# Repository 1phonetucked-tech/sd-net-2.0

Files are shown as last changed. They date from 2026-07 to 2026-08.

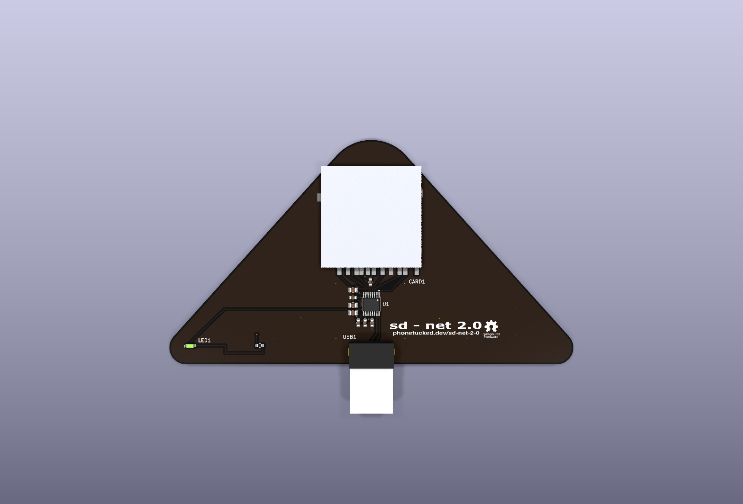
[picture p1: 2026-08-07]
fab/v2.0-kicad/sd-net-2.0-placement-reference.png

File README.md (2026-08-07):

# sd - net 2.0

full-size USB SD card reader > USB-A plug for end user connect > 13 placements across 7 line items in between.

   
rev 2.0 is certified open source hardware by the [Open Source Hardware Association](https://certification.oshwa.org/us002843.html) > UID US002843 > certified 2026-08-07

hardware, everything in `hardware/` and `fab/` > CERN-OHL-S-2.0 > distribute a variant and its design files must be shared under the same terms  
documentation, everything in `docs/` > CC-BY-SA-4.0 > credit the source, share adaptations alike  
software, the generators in `tools/` > GPL-3.0 > see `tools/LICENSE`

| | |
|---|---|
| controller | Genesys Logic GL823K, SSOP-16, LCSC C284879 |
| board | 116.12 × 64.98 mm, 4 layers, 1.6 mm, ENIG |
| finish | black soldermask, white legend |
| placements | 13, of which 12 SMT and 1 through-hole |
| interface | USB 2.0 high speed, SD 4-bit mode |

boards are exclusively given away > not sold.

**shoutout to [PCBWay](https://www.pcbway.com/) who is sponsoring the rev 2.0
run > five boards, fabricated and assembled**

## specifications

**supply**  
1 external rail. GL823K's only rated input is 5 V from VBUS (multimeter tested). VDD and VDDA are outputs of an on-chip band-gap regulator and carry decoupling only > never an external feed. card power is a separate switched net driven from the controller's current-limited output, with its bulk capacitance at the socket so card inrush never reaches the USB PHY rail. **four nets > eight capacitors > no external regulator**  
review [`docs/POWER-DESIGN.md`](docs/POWER-DESIGN.md)

**land patterns**  
KiCad ships no footprint matching any of the three parts on this board > SD-006M (SD slot) > AM90 (USB) > Everlight 12-215SYGC/S530-E2/TR8 (LED). i opted out of pulling them from easyeda2kicad and generated them from the manufacturers' recommended land patterns instead > dimension by dimension > 3D models the same way. every value is recorded in [`docs/LAND-PATTERNS.md`](docs/LAND-PATTERNS.md) > the USB plug's shell tabs sit in correctly sized plated slots rather than oversized round holes > those tabs are the only thing anchoring a board that cantilevers roughly 75 mm out of a host port

**outline**  
isosceles triangle > symmetric about the axis the apex arc and all three connectors sit on > both sides 70.175 mm at 48.007 degrees, with the diagonals constructed as true tangents to the corner fillets

**no external clock**  
controller (GL823K-HCY04) has an on-chip clock source > 12 MHz crystal is not required.

**no card detect**  
by design. controller detects cards by polling the SD bus, which is why the socket's mechanical CD and WP are no connect

## currently

design is DRC clean.  
0 violations and 0 unconnected  
netlist is checked against intent > supply topology is confirmed on hardware at 3.38 V

**rev 2.0 has not been fabricated (yet)**  
[`docs/STATUS.md`](docs/STATUS.md) lists what is verified > what is not > and the checks to run on first articles.  
review before ordering

## layout

| Path | |
|---|---|
| `hardware/` | KiCad 10 project: schematic, PCB, footprints, 3D models |
| `fab/v2.0-kicad/` | Gerbers, drill, BOM, pick-and-place, assembly drawing |
| `docs/` | Power design, land patterns, status |
| `tools/` | Generators and checks |
| `branding/` | OSHW mark and the KiCad colour theme used for the schematic PDF |

## building

the package in `fab/v2.0-kicad/` uploads as-is. Its `README.md` states the
stackup, the plated slots, the non-plated holes and the impedance target for the
fab. To regenerate:

```sh
./tools/gen_fab.py                    # fabrication package
./tools/gen_footprints.py             # footprints
./tools/gen_3dmodels.py               # 3D models
./tools/verify_netlist.py             # netlist against intent
```

`gen_schematic.py` and `gen_pcb.py` built the original KiCad files > kept as a record only > running either overwrites the current board

**do not run `Tools → Update Footprints from Library` in the PCB editor. KiCad
stores pad angles absolutely & `U1` sits at 270 degrees > updating from the library strips those angles and shorts the part**  
*also explained in [`docs/LAND-PATTERNS.md`](docs/LAND-PATTERNS.md)*

created by (1)PhoneTucked.

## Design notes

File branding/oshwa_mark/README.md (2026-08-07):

# Open-source-hardware logo — silkscreen artwork

Prepared for **sd - net** (the plain gear needs no number).

Black (single silkscreen color) version of the classic open-source-hardware gear,
recolored from your `oshw-logo.svg` (OSHW teal `#0099B0` → pure black).

| File | Use |
|---|-----|
| `oshw_gear_13mm.svg` | **Import this** into KiCad — same artwork with real-world dimensions stamped on it (13.0 × 13.661 mm), so `File → Import → Graphics` sizes it correctly instead of guessing a DPI |
| `oshw_gear_black.svg` | Unsized original |
| `oshw_gear_black.png` | 1000 px raster fallback if the SVG import ever misbehaves |

**Target size: 13 mm wide, 10 mm absolute floor.** An earlier version of this file
said 8–12 mm, which was wrong: the artwork is not gear-only, it carries the
"open source hardware" wordmark underneath, and the wordmark is what sets the
minimum. At 13 mm total the wordmark's two lines are roughly 2.2 mm each. Go
much below 10 mm and the thin strokes drop under PCBWay's 0.15 mm silkscreen
minimum, where they print broken or vanish.

Place on a copper-free area — silkscreen over exposed copper gets clipped.
The plain gear logo is free to use on any design that meets the open-source-hardware
definition — no registration or UID required.

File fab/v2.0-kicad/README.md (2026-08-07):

# sd - net 2.0, fabrication package

open-source USB SD card reader. CERN-OHL-S-2.0.
Repository: https://github.com/1phonetucked-tech/sd-net-2.0

| | |
|---|---|
| Board size | **116.12 × 64.98 mm**, shaped outline, not a rectangle |
| Layers | 4 |
| Thickness | 1.6 mm |
| Copper | 1 oz (35 µm) outer and inner |
| Surface finish | **ENIG** |
| Soldermask | **black** |
| Silkscreen | **white** |
| Min track / clearance | 0.20 mm / 0.20 mm |
| Min via | 0.60 mm pad, 0.30 mm drill |
| Placements | **13**, across 7 line items |

## Files

| File | |
|---|---|
| `sd-net-2.0-gerber.zip` | Gerbers + Excellon drill, flat, Protel extensions |
| `sd-net-2.0-bom.csv` | BOM with MPN, manufacturer and LCSC part numbers |
| `sd-net-2.0-cpl.csv` | Pick-and-place |
| `sd-net-2.0-assembly.pdf` | Assembly drawing, legend, part outlines, designators |
| `sd-net-2.0-placement-reference.png` | Render of the finished board |
| `sd-net-2.0-schematic.pdf` | Schematic, for reference |

## Please note when quoting

**1, The outline is not rectangular.** An isosceles triangle with a 13.54 mm
radius arc across the apex and 4.85 mm fillets on the bottom two corners.
Please confirm any profiling or CNC routing charge is included.

**2, One through-hole part, and we do want it populated.** `USB1` is an AM90
right-angle USB-A **male plug**, 6 joints. It falls outside standard SMT
assembly, so please add the hand-soldering as a line item and quote it, rather
than shipping the plug loose. Every board should arrive with `USB1` fitted.
Everything else is SMT.

**3, Two plated slots.** `USB1` MH1/MH2 are **0.90 × 2.25 mm plated slots**,
not round holes. They take the plug's shell tabs and carry the mechanical load,
so please do not substitute round drills.

They are in the drill file, not in the Gerber layers. `sd-net-PTH.drl` cuts them
as Excellon G85 routed slots on tool `T2C0.900`, each routing 1.350 mm along Y
from a centre of Y -95.855, at X 94.155 (MH1) and X 82.445 (MH2). The copper is
on all four layers: obround aperture 1.70 × 3.05 mm flashed at the same two
centres, mask opened to match, both on GND. They are the two oval pads either
side of the four round USB pins. `sd-net-PTH-drl_map.pdf` marks them as well. If
your CAM prefers M15/M16 routed slots or a separate rout layer, say so and we
will send a new drill file.

**4, Four holes must NOT be plated.** `sd-net-NPTH.drl` holds 2 × Ø1.00 mm
(USB plug locating pegs) and 2 × Ø1.60 mm (SD socket pegs). Plating them will
prevent both connectors from seating.

**5, Impedance, as a courtesy check.** `USB_DP` / `USB_DM` on F.Cu are
intended as a 90 Ω differential pair: 0.30 mm wide, 0.346 mm gap, referenced to
In1.Cu, solved against your standard 4-layer 1.6 mm stackup (7628 prepreg,
0.1855 mm after lamination, Dk 4.74). The pair is only ~10 mm long, so this is
not critical, but if your stackup wants a different width or gap, please say
and we will adjust. Note the pair threads a 1.475 mm corridor with 0.265 mm
either side, so widening it needs a layout change on our end.

**6, Please check the CPL rotations against your convention.** The
pick-and-place is KiCad's native output: millimetres, Y negative, rotations in
KiCad's frame. Orientation is the single largest risk on this board, `U1` is
an SSOP-16 where pin 1 must be right, and `LED1` is polarised. If your tooling
expects a different rotation origin, please tell us rather than assuming.

## Two requests

**Five boards first, not the full run.** This revision has never been
fabricated. We would rather find problems on five.

**A photo of the first assembled board before the rest are run.** Compare it
against `sd-net-2.0-placement-reference.png`. Assembly orientation is the
largest remaining risk in this design, and a photo catches it for free.

## About the project

Boards are **given away, not sold**, this is an open-hardware project under
CERN-OHL-S-2.0. Happy to credit PCBWay wherever the project is published.

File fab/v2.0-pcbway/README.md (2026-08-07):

# sd - net 2.0, PCBWay variant

Vendor-specific build of the same board. **Nothing here is a different design.**
Every layer is byte-for-byte identical to `fab/v2.0-kicad/` once Gerber
attribute and comment lines are stripped, and the drill coordinates are the
same to the micron.

Anyone fabricating this board elsewhere should use **`fab/v2.0-kicad/`**, which
is the canonical package. This folder exists because PCBWay asked for two
specific things during the 2026-08 file audit.

## What is different, and why

**1, Gerbers are plain RS-274X, not X2.** PCBWay asked for RS-274X on
2026-08-05. Exported with `--no-x2`, which removes the `%TF` / `%TA` / `%TO` /
`%TD` extended commands. `--no-netlist` is deliberately **not** used: it is not
needed for RS-274X compliance and it would delete the net names. They survive
as ordinary `G04` comments, so netlist-based DFM still works.

**2, The `.gbrjob` file is omitted.** It is part of the X2 family and its
presence invites the same question the RS-274X conversion was meant to settle.

**3, The two `USB1` slots ship in alternative encodings.** They are the only
non-round feature on the board, and the only part of the package queried during
the audit. `sd-net-2.0-drill-alternates.zip` holds the same two slots written
two other ways, so a CAM system can take whichever slot convention it prefers.

## Files

| File | |
|---|---|
| `sd-net-2.0-gerber-rs274x.zip` | Gerbers + Excellon drill, RS-274X, no `.gbrjob` |
| `sd-net-2.0-drill-alternates.zip` | Slot alternatives, see below |

Inside `sd-net-2.0-drill-alternates.zip`:

| File | |
|---|---|
| `sd-net-PTH-M15M16.drl` | Plated drill with the slots as M15/M16 routed slots instead of `G85`. Identical to `sd-net-PTH.drl` in every other respect |
| `sd-net-PTH-drl.gbr` | Drill data plotted as a Gerber layer, so every hole is visible in an ordinary viewer |
| `sd-net-NPTH-drl.gbr` | The same, non-plated |

**Only one plated drill file may be loaded**, either `sd-net-PTH.drl` from the
main zip or `sd-net-PTH-M15M16.drl` from the alternates. Both describe the same
two slots, so loading both would double them.

The two `.gbr` files are for viewing and cross-checking only. They are not a
fabrication layer and must not be used as one.

## The slots

All three encodings describe one geometry: a 0.90 mm tool travelling 1.350 mm
along Y, giving a **0.90 x 2.25 mm plated slot**, long axis vertical.

| | Centre | Extent along Y |
|---|---|---|
| MH1 | X 94.155, Y -95.855 | -94.730 → -96.980 |
| MH2 | X 82.445, Y -95.855 | -94.730 → -96.980 |

Copper is an obround 1.70 x 3.05 mm flashed at the same two centres on all four
layers, mask opened to match, both on GND.

## Hole inventory

| File | Tool | Size | Count | |
|---|---|---|---|---|
| PTH | T1 | Ø0.300 mm | 20 | vias |
| PTH | T3 | Ø1.001 mm | 4 | `USB1` signal pins |
| PTH | T2 | 0.90 x 2.25 mm slot | 2 | `USB1` shell tabs |
| NPTH | T1 | Ø1.000 mm | 2 | `USB1` locating pegs |
| NPTH | T2 | Ø1.600 mm | 2 | SD socket pegs |

26 plated including the two slots, 4 non-plated, 30 total. **The four NPTH must
stay unplated** or neither connector will seat.

## Regenerating

    ./tools/gen_fab.py --pcbway

Builds this folder and touches nothing else. The quoting notes, BOM, CPL and
assembly drawing are not duplicated here: they live in `fab/v2.0-kicad/` and
are not vendor-specific.

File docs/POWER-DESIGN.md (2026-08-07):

# Power design

The GL823K takes a single external supply. Everything else on the board is
generated inside the chip.

Section and table numbers below refer to the GL823K datasheet rev 1.05. That
document is Genesys Logic's and is not redistributed here: request it through
the vendor, or through LCSC part C284879.

## Supply topology

Four nets, each with its own decoupling, and no external connection between
them.

: `+5V` : `USB1.1` to `U1.10`. The only external supply. C1 10 uF + C4 100 nF
: `VDD` : `U1.9`. Regulator output. Decouple only. C2 10 uF + C5 100 nF
: `VDDA` : `U1.13`. Regulator output feeding the USB PHY. Decouple only, keep
  the loop tight. C6 + C8 100 nF
: `VCARD` : `U1.8` to `CARD1.4`. Switched output. C3 10 uF + C7 100 nF, placed
  at the socket

## Why VDD and VDDA are not supplied externally

The datasheet lists exactly one supply. Table 5.2 gives an operating range of
+4.75 V to +5.25 V, and Table 5.3 lists one entry, `V5`. Neither VDD nor VDDA
appears anywhere in the electrical characteristics. Section 4.6 describes an
on-chip 5 V to 3.3 V band-gap regulator supplying the USB PHY and PMOS, and
section 4.7 describes on-chip power MOSFETs for memory card power.

VDD and VDDA are therefore outputs. Driving them from an external rail would
fight the internal regulator.

Confirmed on hardware, 2026-08-02. With only 5 V applied, VBUS measured at
5.17 V, the 3.3 V node reads 3.38 V, which is within the tolerance expected of a
band-gap reference. Nothing external supplies that node, so the regulator is
producing it.

The Rev 1.05 datasheet contains no typical application circuit and no
recommended decoupling values. The topology above follows from the electrical
tables; the capacitor values are engineering judgement.

## Why VDD and VDDA are not tied to each other

Decouple each separately at its own pin and run no external link between them.
This holds under either internal arrangement:

: If they are internally common, an external link is redundant and omitting it
  costs nothing
: If they are internally separate, an external link defeats that isolation and
  couples digital and card-interface switching noise into the USB 2.0 PHY rail

## Card power

`PMOS`, pin 8, is a switched current-limited output rated 200 mA. It is not a
supply rail and must drive the card only.

Bulk and high-frequency capacitance for the card sits at the socket rather than
at the controller, so card inrush is absorbed locally and does not reach VDD or
VDDA.

## Clock

No external crystal. The GL823K contains an on-chip clock source, so no 12 MHz
oscillator is required.

## LED

`R1`, 220 R, is fed from VDD, so the LED runs on 3.3 V and requires a forward
voltage at or below roughly 2.4 V. The specified part is a yellow-green AlInGaP
device at 1.7-2.4 V, giving about 5.5 mA. A pure green InGaN LED with a 3.3 V
forward voltage will not light on this rail.

The cathode returns to `U1.12`, an open-drain output. The LED indicates power
and bus activity, not card presence.

## Card detect

There is deliberately no card-detect connection. The datasheet feature list
advertises support for a non-SD-card-detect design; the controller detects cards
by polling the SD bus. Pin 11 is a general purpose I/O with an internal pull-up
and no documented card-presence function.

`CARD1.CD` and `CARD1.WP` are left unconnected with explicit no-connect markers.
`CARD1.1` is used as DAT3; that contact doubles as card detect only in SPI mode,
and this design uses 4-bit SD mode.

## Grounding

`USB1` shell tabs `MH1` and `MH2`, and SD socket shell tabs `CARD1.12` and
`CARD1.13`, are tied to GND.

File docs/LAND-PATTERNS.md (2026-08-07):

# Land patterns

KiCad ships no footprint matching any of the three parts below, so all three
are generated by `tools/gen_footprints.py` from the dimensions recorded here.
Every value comes from the manufacturer's recommended land pattern.

KiCad does carry six full-size SD sockets in `Connector_Card`, from TE, Hirose
and Kyocera, but none share the SD-006M's contact count, shell tabs or peg
positions. Full-size SD sockets are not interchangeable between manufacturers.

Coordinates are millimetres in each footprint's own frame, Y positive downward.

## SD-006M

SOFNG full-size SD socket, push-push, LCSC C125615. Datasheet page 2,
"CIRCUIT BOARD SIZE (Vertical view)".

| Dimension | Value |
|---|---|
| Contact row → peg holes | 24.60 |
| Peg hole spacing | 24.20, at ±12.10 |
| Peg hole diameter | 1.60 non-plated (specified 1.50) |
| GROUND1 → peg holes, Y | 2.10 |
| GROUND2 above GROUND1 | 1.20 |
| Contact pad | 1.1989 × 2.1996 (specified 1.20 × 2.00) |
| Shell tab pad | 1.999 × 2.3012 (specified 1.70 × 2.00) |

Contact X positions, referenced to pad 9:

| Contact | Offset from #9 |
|---|---|
| #1 | 2.50 |
| #2 | 5.00 |
| CD | 6.43 |
| #3 | 8.30 |
| #4 | 10.00 |
| #5 | 12.50 |
| #6 | 15.00 |
| #7 | 17.43 |
| #8 | 19.13 |
| WP | 22.38 |

The row is not evenly pitched. Gaps run 2.50 between #6, #5 and #4, then 2.43
from #7 to #6, 1.70 from #8 to #7, and 3.25 from WP to #8.

The two shell tabs are not mirror images. The right tab sits further out and
1.20 mm nearer the contact row than the left.

Pads are drawn larger than specified, contacts by 0.20 in length and shell tabs
by 0.30 in both axes. The extra area is solder fillet and is deliberate.

The socket body is 29.0 × 28.5 × 2.9 mm. Its two front corners overhang the
board edge by up to 1.14 mm over the last 1.3 mm of its length, where the board
outline has not yet widened past the 28.5 mm body.

## USB-AM90

Shou Han right-angle USB-A male plug, LCSC C404965. Drawing A/0 dated
2018.07.10, PCB layout view.

| Dimension | Value |
|---|---|
| Signal pin spacing | 2.50 / 2.00 / 2.50, spanning 7.00 |
| Signal hole diameter | 1.00 |
| Pin row → peg and tab row | 2.00 |
| Locating peg spacing | 4.50, at ±2.25 |
| Locating peg diameter | 1.00 non-plated |
| Shell tab spacing | 11.70, at ±5.855 |
| Shell tab opening | 0.90 × 2.25 plated slot (specified 0.86 × 2.20) |

The AM90 has no mounting posts. Its shell ends in two flat 0.86 mm tabs that
belong in slots, and those tabs are the only mechanical anchorage for a board
that cantilevers roughly 75 mm out of a USB port. Slots are cut 0.04 mm over the
specified opening to leave room for hole plating.

Peg clearance is tight. A 0.85 mm peg in a 1.00 mm hole leaves 0.05-0.075 mm
radially, so the 2.00 mm offset from the pin row must be held or the plug will
bind rather than seat flat.

## LED-12-215SYGC

Everlight 12-215SYGC/S530-E2/TR8 yellow-green chip LED, LCSC C131283.

| Dimension | Value |
|---|---|
| Body | 2.0 × 1.0 × 0.8, an 0804 |
| Pad | 0.8992 × 0.8001 at ±1.0503 |
| Polarity | pad 1 is the cathode, on -x |

An 0804 is outside the metric chip series, so no stock land fits. The terminals
sit 0.60-1.00 mm out from the centre, which a 1.6 mm 0603 land does not reach
properly.

The footprint carries a silkscreen bar outside pad 1. Chip LEDs have no legible
marking once placed, so the board has to state polarity.

## U1

`U1` uses stock `Package_SO:SSOP-16_3.9x4.9mm_P0.635mm`: pads 1.65 × 0.40 on
0.635 mm pitch with rows at ±2.625. IPC-correct for the package.

Pad rotation angles are stored absolutely in KiCad, with the footprint's
placement rotation baked in. `U1` sits at 270 degrees, so its instance carries
pad angles its library copy does not.

Running `Tools → Update Footprints from Library` strips those angles and shorts
the board: the pad positions stay rotated while the pad shapes do not, and
`U1`'s 1.65 mm pads then lie across a 0.635 mm pitch. Re-run
`tools/gen_pcb.py` instead, and re-check DRC.

## Regenerating

`gen_footprints.py` derives each courtyard from the pad extents, so any pad
change also changes the courtyard. Board footprint instances carry their own
copy of that rectangle. After re-running the generator, sync pad positions and
both `fp_rect` entries in each instance, then refill zones with
`kicad-cli pcb drc --refill-zones --save-board`. Stale zone fill otherwise
appears as clearance errors around whatever moved.

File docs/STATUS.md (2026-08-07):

# Status and open items

Rev 2.0 has not been fabricated. Everything below distinguishes what has been
verified from what has not.

## Verified

: DRC 0 violations, 0 unconnected, with `missing_courtyard` and
  `track_not_centered_on_via` enabled
: Netlist checked against intent by `tools/verify_netlist.py`, 15 nets
: Supply topology confirmed on hardware at 3.38 V, see `POWER-DESIGN.md`
: All three land patterns measured against the manufacturers' drawings, see
  `LAND-PATTERNS.md`
: No external crystal required, the controller has an on-chip clock source
: Fabrication package regenerates byte-identical apart from embedded timestamps

## Not verified

**Nothing in this design has run.** No board has been fabricated. DRC and
netlist checks confirm the design matches its intent; they say nothing about
whether the intent is correct.

## Open items

### Assembly orientation

The largest remaining risk. `U1` is an SSOP-16 where pin 1 must be correct, and
`LED1` is polarised. The pick-and-place file uses KiCad's native convention:
millimetres, Y negative, rotations in KiCad's frame.

Ask the assembler to confirm the rotation convention rather than assume it, and
to send a photograph of the first assembled board for comparison against
`fab/v2.0-kicad/sd-net-2.0-placement-reference.png`.

### Mechanical

The board is 116.12 × 64.98 mm hanging off a single USB-A plug, roughly 75 mm of
overhang once inserted. A knock puts leverage on both the plug's solder joints
and the host port.

The shell tabs now sit in correctly sized plated slots rather than oversized
round holes, which is what carries that load. The lever arm is unchanged.

### Differential pair impedance

`USB_DP` and `USB_DM` are intended as a 90 R differential pair: 0.30 mm wide,
0.346 mm gap on F.Cu, referenced to In1.Cu, solved with IPC-2141 against a
standard 4-layer 1.6 mm stackup, 7628 prepreg at 0.1855 mm after lamination,
Dk 4.74.

This is a first-order closed-form approximation rather than a 2D field solve.
It is also not critical: the routed pair measures 10.11 mm and 9.50 mm, roughly
63 ps of flight time against USB 2.0's 500 ps rise time, below the point at
which a trace behaves as a transmission line. Intra-pair skew is about 4 ps.

Worth asking a fab to check against their production stackup, but not a gate. If
a different width or gap is required, note the pair threads a 1.475 mm corridor
with 0.265 mm either side, so widening it needs C6 to move.

### SD socket overhang

The socket body overhangs the board edge by up to 1.14 mm at its two front
corners. Within the tolerance of the modelled body position, so it needs
checking against a physical part rather than correcting blind.

## First article checks

1. Plug into a host and confirm the device enumerates.
2. Insert a card and confirm it mounts.
3. Measure `VCARD` at `CARD1` pin 4. It must come up under the controller's
   control rather than sitting hard-tied to the 3.3 V rail. This is the single
   most informative measurement on the board.
4. Confirm the LED lights on power and flickers during transfer. It indicates
   power and access, not card presence.

## Order quantity

Order five, not thirty. Every open item above is cheap to discover on five
boards and expensive to discover on thirty.

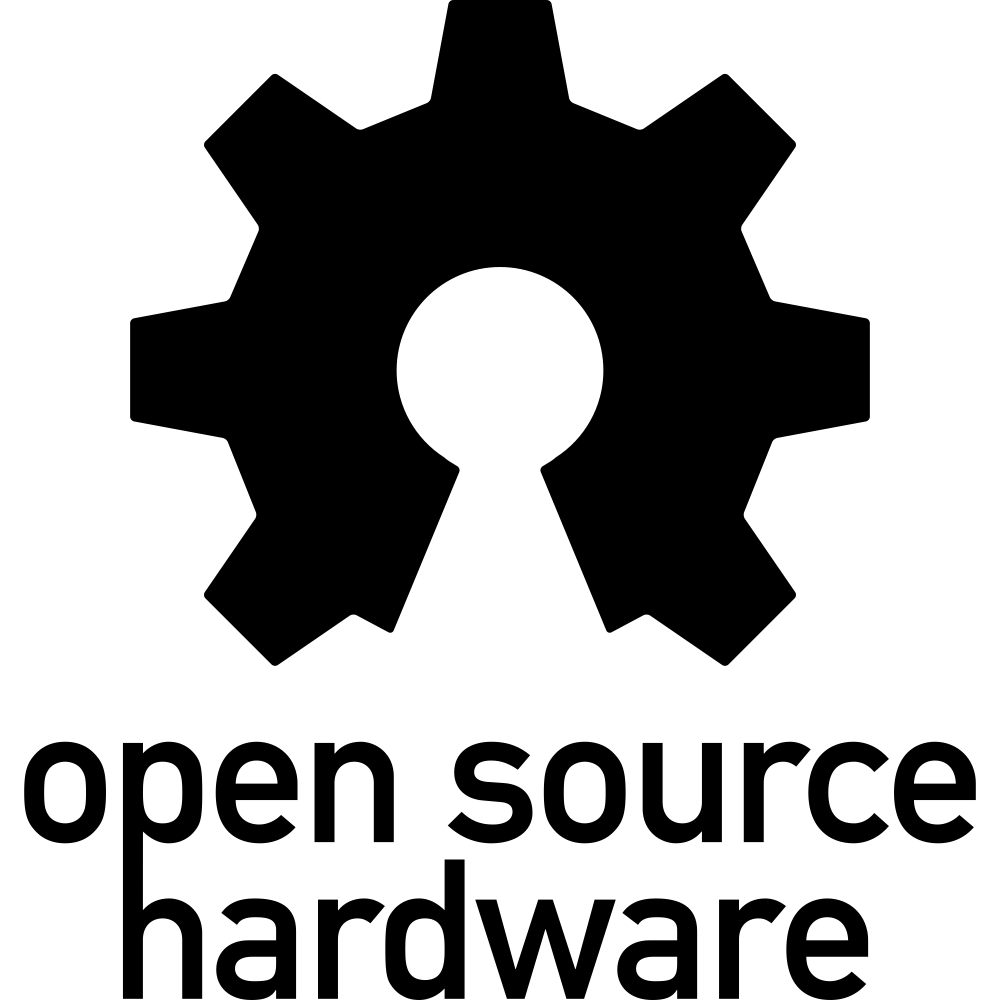
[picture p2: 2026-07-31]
branding/oshwa_mark/oshw_gear_black.png

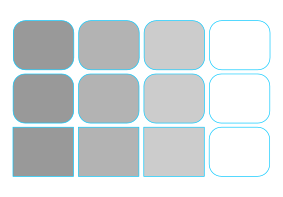
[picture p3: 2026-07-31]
branding/stickerclear4.png

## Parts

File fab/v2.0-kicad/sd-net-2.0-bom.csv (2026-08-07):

Designator | Value | Footprint | MPN | Manufacturer | LCSC Part # | Quantity
C1-C3 | 10uF | Capacitor_SMD:C_0805_2012Metric | CL21A106KAYNNNE | Samsung | C15850 | 3
C4-C8 | 100nF | Capacitor_SMD:C_0603_1608Metric | CC0603KRX7R9BB104 | Yageo | C14663 | 5
CARD1 | SD-006M | sd-net:SD-006M | SD-006M | Sofng | C125615 | 1
LED1 | 12-215SYGC | sd-net:LED-12-215SYGC | 12-215SYGC/S530-E2/TR8 | Everlight | C131283 | 1
R1 | 220 | Resistor_SMD:R_0603_1608Metric | 0603WAF2200T5E | Uni-Royal | C22962 | 1
U1 | GL823K-HCY04 | Package_SO:SSOP-16_3.9x4.9mm_P0.635mm | GL823K-HCY04 | Genesys Logic | C284879 | 1
USB1 | AM90 | sd-net:USB-AM90 | AM90 | Shou Han | C404965 | 1

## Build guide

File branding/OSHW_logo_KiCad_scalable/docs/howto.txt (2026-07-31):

How to make your own:
---------------------

Watch / read this first:

* http://www.kicad-pcb.org/display/KICAD/Videos+by+zupnikal

The last two videos should be helpful for how to create a custom .emp file from images.

* http://www.re-innovation.co.uk/web12/index.php/en/blog-75/230-adding-logo-to-kicad

If you use linux (which you should), you don't have to use the online-scaler. Just use the scripts!

---

* Create a folder to hold your new footprint library.
* Copy the scripts 'make_lib.sh' and 'scale.pl' into that folder.
* Make sure these files are executable (chmod u+x ...).
* Copy your custom .emp file into that foler.

* Run the 'make_lib.sh' script as follows:

./make_lib.sh input-file.emp lib-name.mod START END

START and END are placeholders for positive integer numbers (1,2,3...) that determine
the range of created footprint sizes. The units are metric (mm).

The 'lib-name.mod' file will show up in the 'lib' sub-folder. Add it to your pcbnew
library settings as usual.

Footprints that are created for back-layers are automagically mirrored horizontally.
To place them onto a back-layer, hover the mouse-pointer over them and press 'f' for 'flip'.

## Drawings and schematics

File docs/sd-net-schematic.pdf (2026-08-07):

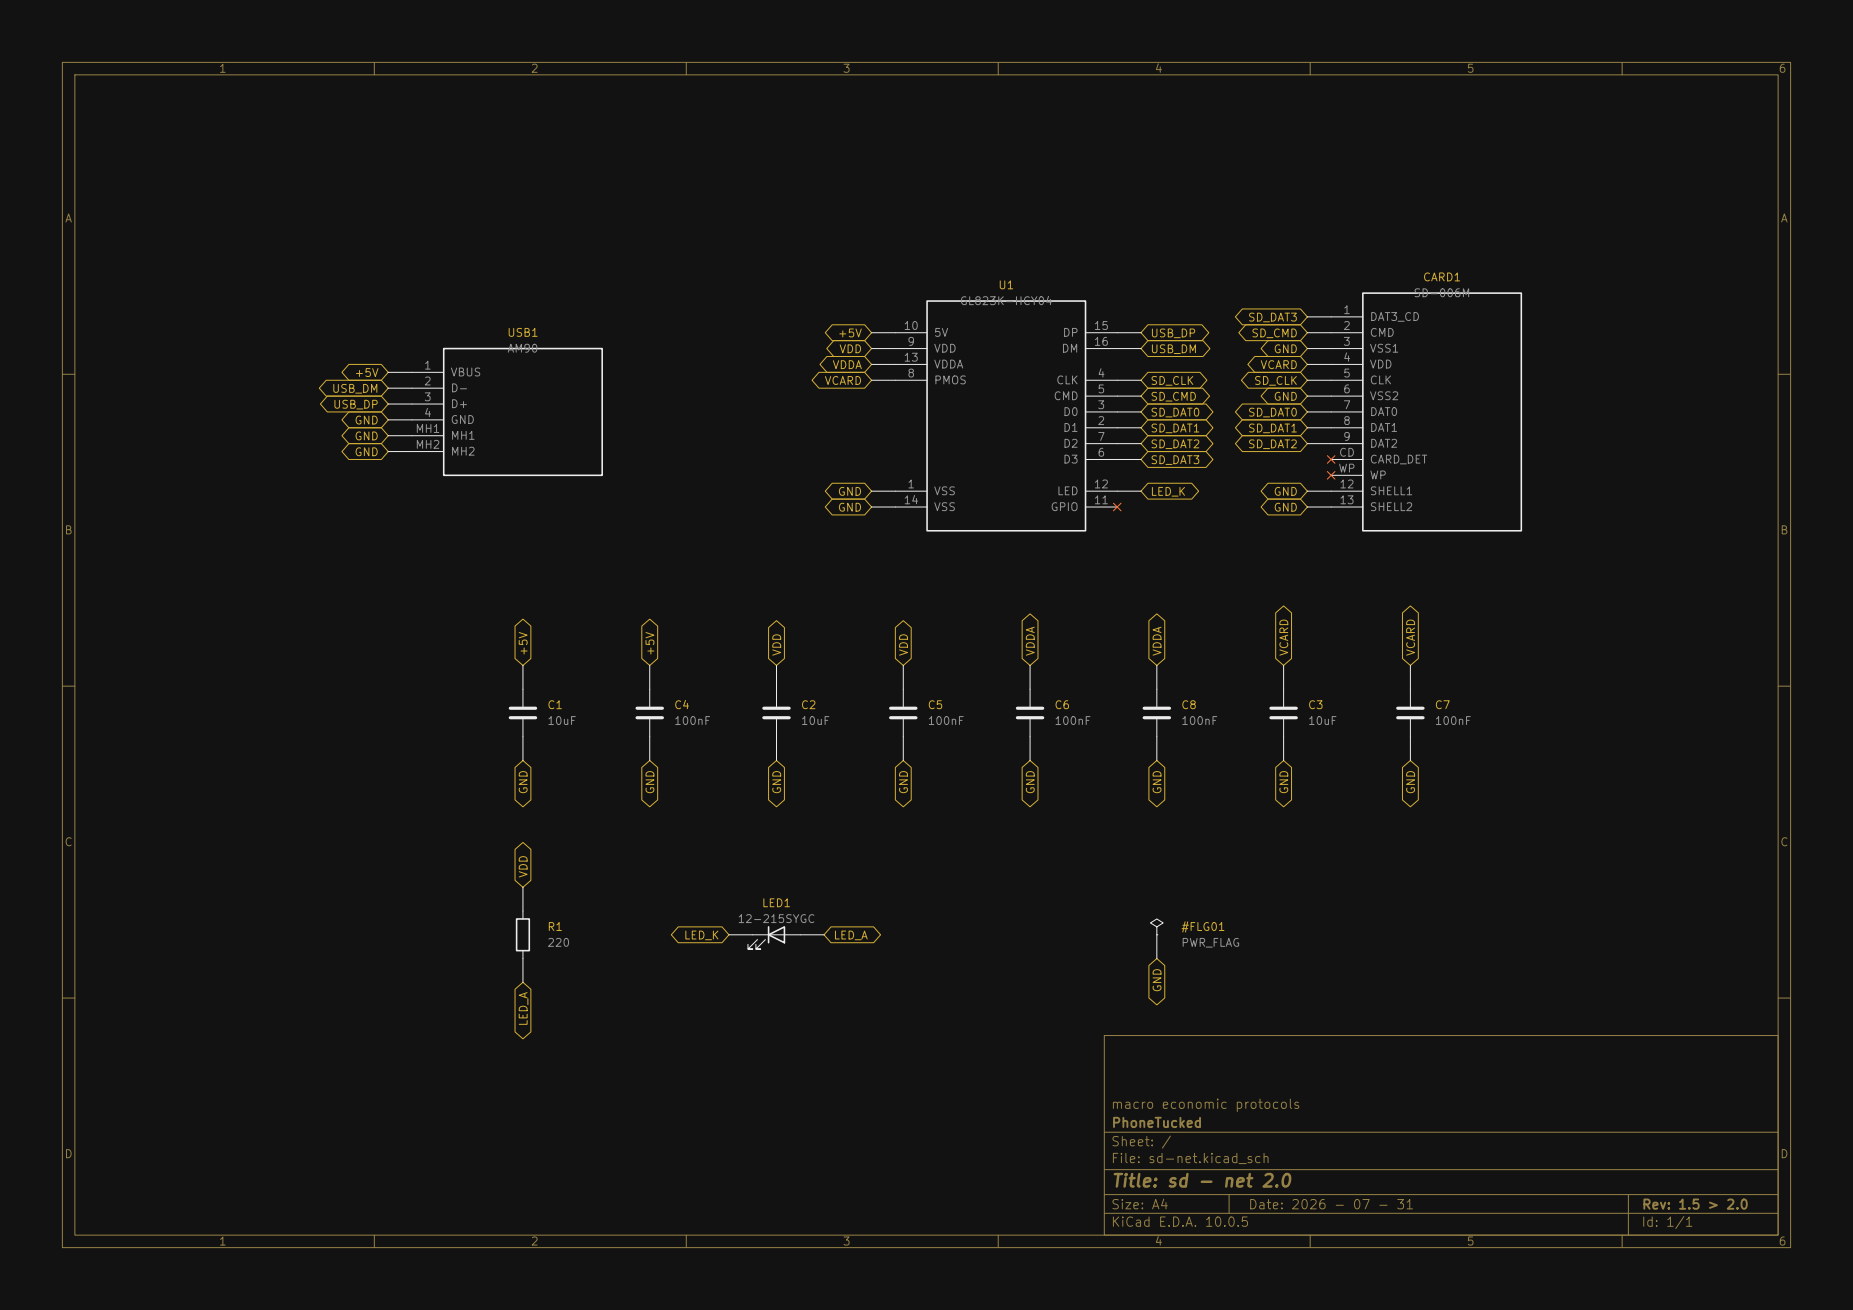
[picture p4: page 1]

Size: A4 | Rev: 1.5 > 2.0
KiCad E.D.A. 10.0.5 | Id: 1/1

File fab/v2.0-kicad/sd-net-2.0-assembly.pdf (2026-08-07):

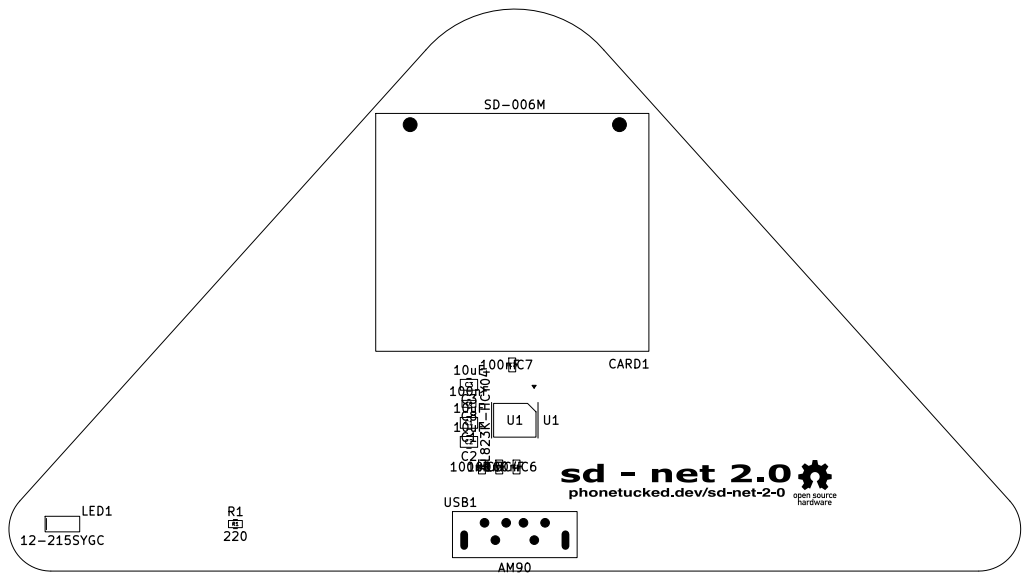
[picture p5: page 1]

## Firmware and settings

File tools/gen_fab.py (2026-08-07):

#!/usr/bin/env python3
"""Build the rev 2.0 fabrication package.

produces everything PCBWay needs to quote and build the board, in the shape
they expect it: **Gerbers and drill files zipped together**, with the BOM and
pick-and-place alongside as loose CSVs.

    ./tools/gen_fab.py                      # -> fab/v2.0-kicad/
    ./tools/gen_fab.py EXTRA_DIR ...        # also copy the package to EXTRA_DIR
    ./tools/gen_fab.py --pcbway             # -> fab/v2.0-pcbway/ only

`--pcbway` builds the vendor variant and touches nothing else, so the canonical
package can sit untouched while an order is in audit. See
`fab/v2.0-pcbway/README.md` for why that folder exists.

Gerber conventions chosen deliberately:
  * protel extensions (.GTL/.GBL/...) rather than .gbr. Every fab reads both;
    Protel is what PCBWay's own documentation shows.
  * x2 attributes left ON. They carry net and pad function metadata, which is
    what lets a fab's DFM tooling tell a via from a pad. The PCBWay variant
    turns them off, see build_pcbway().
  * soldermask subtracted from silkscreen, so legend never prints onto bare
    copper.
  * absolute origin for both Gerbers and drill, so the two always agree.
  * PTH and NPTH in separate files > board has NPTH that matters (the
    connector locating pegs), and merging them invites a fab to plate holes
    that must not be plated.
"""

import os
import re
import shutil
import subprocess
import sys
import tempfile
import zipfile

HERE = os.path.dirname(os.path.dirname(os.path.abspath(__file__)))
PCB = os.path.join(HERE, "hardware", "sd-net.kicad_pcb")
SCH = os.path.join(HERE, "hardware", "sd-net.kicad_sch")
OUT = os.path.join(HERE, "fab", "v2.0-kicad")
PCBWAY_OUT = os.path.join(HERE, "fab", "v2.0-pcbway")
CLI = "/Applications/KiCad/KiCad.app/Contents/MacOS/kicad-cli"

# Gerber X2 attribute commands. Stripping these leaves plain RS-274X: the
# image data is untouched and the same metadata survives as G04 comments.
X2_CMD = re.compile(r"^%T[FAOD]")

LAYERS = ("F.Cu,In1.Cu,In2.Cu,B.Cu,"
          "F.Paste,B.Paste,F.SilkS,B.SilkS,F.Mask,B.Mask,Edge.Cuts")

BOM_FIELDS = "Reference,Value,Footprint,MPN,Manufacturer,LCSC,${QUANTITY}"
BOM_LABELS = "Designator,Value,Footprint,MPN,Manufacturer,LCSC Part #,Quantity"


README = """# sd - net 2.0, fabrication package

open-source USB SD card reader. CERN-OHL-S-2.0.
Repository: https://github.com/1phonetucked-tech/sd-net-2.0

| | |
|---|---|
| Board size | **116.12 × 64.98 mm**, shaped outline, not a rectangle |
| Layers | 4 |
| Thickness | 1.6 mm |
| Copper | 1 oz (35 µm) outer and inner |
| Surface finish | **ENIG** |
| Soldermask | **black** |
| Silkscreen | **white** |
| Min track / clearance | 0.20 mm / 0.20 mm |
| Min via | 0.60 mm pad, 0.30 mm drill |
| Placements | **13**, across 7 line items |

## Files

| File | |
|---|---|
| `sd-net-2.0-gerber.zip` | Gerbers + Excellon drill, flat, Protel extensions |
| `sd-net-2.0-bom.csv` | BOM with MPN, manufacturer and LCSC part numbers |
| `sd-net-2.0-cpl.csv` | Pick-and-place |
| `sd-net-2.0-assembly.pdf` | Assembly drawing, legend, part outlines, designators |
| `sd-net-2.0-placement-reference.png` | Render of the finished board |
| `sd-net-2.0-schematic.pdf` | Schematic, for reference |

## Please note when quoting

**1, The outline is not rectangular.** An isosceles triangle with a 13.54 mm
radius arc across the apex and 4.85 mm fillets on the bottom two corners.
Please confirm any profiling or CNC routing charge is included.

**2, One through-hole part, and we do want it populated.** `USB1` is an AM90
right-angle USB-A **male plug**, 6 joints. It falls outside standard SMT
assembly, so please add the hand-soldering as a line item and quote it, rather
than shipping the plug loose. Every board should arrive with `USB1` fitted.
Everything else is SMT.

**3, Two plated slots.** `USB1` MH1/MH2 are **0.90 × 2.25 mm plated slots**,
not round holes. They take the plug's shell tabs and carry the mechanical load,
so please do not substitute round drills.

**4, Four holes must NOT be plated.** `sd-net-NPTH.drl` holds 2 × Ø1.00 mm
(USB plug locating pegs) and 2 × Ø1.60 mm (SD socket pegs). Plating them will
prevent both connectors from seating.

**5, Impedance, as a courtesy check.** `USB_DP` / `USB_DM` on F.Cu are
intended as a 90 Ω differential pair: 0.30 mm wide, 0.346 mm gap, referenced to
In1.Cu, solved against your standard 4-layer 1.6 mm stackup (7628 prepreg,
0.1855 mm after lamination, Dk 4.74). The pair is only ~10 mm long, so this is
not critical, but if your stackup wants a different width or gap, please say
and we will adjust. Note the pair threads a 1.475 mm corridor with 0.265 mm
either side, so widening it needs a layout change on our end.

**6, Please check the CPL rotations against your convention.** The
pick-and-place is KiCad's native output: millimetres, Y negative, rotations in
KiCad's frame. Orientation is the single largest risk on this board, `U1` is
an SSOP-16 where pin 1 must be right, and `LED1` is polarised. If your tooling
expects a different rotation origin, please tell us rather than assuming.

## Two requests

**Five boards first, not the full run.** This revision has never been
fabricated. We would rather find problems on five.

**A photo of the first assembled board before the rest are run.** Compare it
against `sd-net-2.0-placement-reference.png`. Assembly orientation is the
largest remaining risk in this design, and a photo catches it for free.

## About the project

Boards are **given away, not sold**, this is an open-hardware project under
CERN-OHL-S-2.0. Happy to credit PCBWay wherever the project is published.
"""


def run(*args):
    r = subprocess.run([CLI] + list(args), capture_output=True, text=True)
    if r.returncode != 0:
        sys.exit(f"FAILED: {' '.join(args[:3])}\n{r.stdout}\n{r.stderr}")


def build():
    gerber_dir = os.path.join(OUT, "gerber")
    shutil.rmtree(gerber_dir, ignore_errors=True)
    os.makedirs(gerber_dir, exist_ok=True)

    run("pcb", "export", "gerbers", "--layers", LAYERS,
        "--subtract-soldermask", "--precision", "6", "-o", gerber_dir + "/", PCB)
    run("pcb", "export", "drill", "--format", "excellon",
        "--drill-origin", "absolute", "--excellon-separate-th",
        "--excellon-zeros-format", "decimal", "--generate-map",
        "--map-format", "pdf", "-o", gerber_dir + "/", PCB)

    # Zip exactly the Gerber + drill set, flat -- fabs expect no nesting.
    zip_path = os.path.join(OUT, "sd-net-2.0-gerber.zip")
    with zipfile.ZipFile(zip_path, "w", zipfile.ZIP_DEFLATED) as z:
        for f in sorted(os.listdir(gerber_dir)):
            z.write(os.path.join(gerber_dir, f), f)
    n = len(zipfile.ZipFile(zip_path).namelist())

    run("pcb", "export", "pos", "--format", "csv", "--units", "mm",
        "--side", "both", "-o", os.path.join(OUT, "sd-net-2.0-cpl.csv"), PCB)
    run("sch", "export", "bom", "--fields", BOM_FIELDS, "--labels", BOM_LABELS,
        "--group-by", "Value,MPN,Footprint", "--sort-field", "Reference",
        "-o", os.path.join(OUT, "sd-net-2.0-bom.csv"), SCH)

    sch_pdf = os.path.join(HERE, "docs", "sd-net-schematic.pdf")
    if os.path.exists(sch_pdf):
        shutil.copy2(sch_pdf, os.path.join(OUT, "sd-net-2.0-schematic.pdf"))

    # Assembly drawing: legend, fab outlines and board edge, with designators.
    run("pcb", "export", "pdf", "--mode-single",
        "--layers", "F.SilkS,F.Fab,Edge.Cuts", "--black-and-white",
        "-o", os.path.join(OUT, "sd-net-2.0-assembly.pdf"), PCB)

    # A picture of the finished board. Not a formal deliverable, but it is the
    # cheapest way for an assembly house to check orientation at a glance --
    # U1's pin 1, the LED, which way the connectors face. Needs the models
    # from gen_3dmodels.py; skipped silently if they are gone.
    run("pcb", "render", "--side", "top", "--perspective",
        "--use-board-stackup-colors", "--zoom", "0.8", "--quality", "high",
        "-w", "1600", "-h", "1100", "--background", "opaque",
        "-o", os.path.join(OUT, "sd-net-2.0-placement-reference.png"), PCB)

    open(os.path.join(OUT, "README.md"), "w").write(README)

    print(f"gerber+drill : {n} files -> {os.path.relpath(zip_path, HERE)}")
    return zip_path


PCBWAY_README = """# sd - net 2.0, PCBWay variant

Vendor-specific build of the same board. **Nothing here is a different design.**
Every layer is byte-for-byte identical to `fab/v2.0-kicad/` once Gerber
attribute and comment lines are stripped, and the drill coordinates are the
same to the micron.

Anyone fabricating this board elsewhere should use **`fab/v2.0-kicad/`**, which
is the canonical package. This folder exists because PCBWay asked for two
specific things during the 2026-08 file audit.

## What is different, and why

**1, Gerbers are plain RS-274X, not X2.** PCBWay asked for RS-274X on
2026-08-05. Exported with `--no-x2`, which removes the `%TF` / `%TA` / `%TO` /
`%TD` extended commands. `--no-netlist` is deliberately **not** used: it is not
needed for RS-274X compliance and it would delete the net names. They survive
as ordinary `G04` comments, so netlist-based DFM still works.

**2, The `.gbrjob` file is omitted.** It is part of the X2 family and its
presence invites the same question the RS-274X conversion was meant to settle.

**3, The two `USB1` slots ship in alternative encodings.** They are the only
non-round feature on the board, and the only part of the package queried during
the audit. `sd-net-2.0-drill-alternates.zip` holds the same two slots written
two other ways, so a CAM system can take whichever slot convention it prefers.

## Files

| File | |
|---|---|
| `sd-net-2.0-gerber-rs274x.zip` | Gerbers + Excellon drill, RS-274X, no `.gbrjob` |
| `sd-net-2.0-drill-alternates.zip` | Slot alternatives, see below |

Inside `sd-net-2.0-drill-alternates.zip`:

| File | |
|---|---|
| `sd-net-PTH-M15M16.drl` | Plated drill with the slots as M15/M16 routed slots instead of `G85`. Identical to `sd-net-PTH.drl` in every other respect |
| `sd-net-PTH-drl.gbr` | Drill data plotted as a Gerber layer, so every hole is visible in an ordinary viewer |
| `sd-net-NPTH-drl.gbr` | The same, non-plated |

**Only one plated drill file may be loaded**, either `sd-net-PTH.drl` from the
main zip or `sd-net-PTH-M15M16.drl` from the alternates. Both describe the same
two slots, so loading both would double them.

The two `.gbr` files are for viewing and cross-checking only. They are not a
fabrication layer and must not be used as one.

## The slots

All three encodings describe one geometry: a 0.90 mm tool travelling 1.350 mm
along Y, giving a **0.90 x 2.25 mm plated slot**, long axis vertical.

| | Centre | Extent along Y |
|---|---|---|
| MH1 | X 94.155, Y -95.855 | -94.730 → -96.980 |
| MH2 | X 82.445, Y -95.855 | -94.730 → -96.980 |

Copper is an obround 1.70 x 3.05 mm flashed at the same two centres on all four
layers, mask opened to match, both on GND.

## Hole inventory

| File | Tool | Size | Count | |
|---|---|---|---|---|
| PTH | T1 | Ø0.300 mm | 20 | vias |
| PTH | T3 | Ø1.001 mm | 4 | `USB1` signal pins |
| PTH | T2 | 0.90 x 2.25 mm slot | 2 | `USB1` shell tabs |
| NPTH | T1 | Ø1.000 mm | 2 | `USB1` locating pegs |
| NPTH | T2 | Ø1.600 mm | 2 | SD socket pegs |

26 plated including the two slots, 4 non-plated, 30 total. **The four NPTH must
stay unplated** or neither connector will seat.

## Regenerating

    ./tools/gen_fab.py --pcbway

Builds this folder and touches nothing else. The quoting notes, BOM, CPL and
assembly drawing are not duplicated here: they live in `fab/v2.0-kicad/` and
are not vendor-specific.
"""


def _strip_x2(src, dst):
    """Copy a Gerber, dropping X2 attribute commands. Image data untouched."""
    with open(src) as f:
        kept = [ln for ln in f if not X2_CMD.match(ln)]
    with open(dst, "w") as f:
        f.writelines(kept)


def build_pcbway():
    """Vendor variant: RS-274X Gerbers, plus the slots in other encodings.

    Deliberately independent of build(). It never writes into fab/v2.0-kicad/,
    so this can be regenerated while an order is in audit without churning the
    package the fab is already holding.
    """
    os.makedirs(PCBWAY_OUT, exist_ok=True)

    with tempfile.TemporaryDirectory() as tmp:
        main_dir = os.path.join(tmp, "main")
        alt_dir = os.path.join(tmp, "alt")
        os.makedirs(main_dir)
        os.makedirs(alt_dir)

        # RS-274X set. --no-netlist is deliberately absent: not required for
        # RS-274X, and it would throw away the net names that DFM relies on.
        run("pcb", "export", "gerbers", "--layers", LAYERS,
            "--subtract-soldermask", "--precision", "6", "--no-x2",
            "-o", main_dir + "/", PCB)
        run("pcb", "export", "drill", "--format", "excellon",
            "--drill-origin", "absolute", "--excellon-separate-th",
            "--excellon-zeros-format", "decimal", "--generate-map",
            "--map-format", "pdf", "-o", main_dir + "/", PCB)

        # The job file is X2 family; shipping it reopens the question the
        # RS-274X conversion exists to close.
        job = os.path.join(main_dir, "sd-net-job.gbrjob")
        if os.path.exists(job):
            os.remove(job)

        main_zip = os.path.join(PCBWAY_OUT, "sd-net-2.0-gerber-rs274x.zip")
        with zipfile.ZipFile(main_zip, "w", zipfile.ZIP_DEFLATED) as z:
            for f in sorted(os.listdir(main_dir)):
                z.write(os.path.join(main_dir, f), f)

        # Slot alternatives. KiCad's flag names read backwards here: the
        # default "alternate" is G85, and "route" is what emits M15/M16.
        route_dir = os.path.join(tmp, "route")
        os.makedirs(route_dir)
        run("pcb", "export", "drill", "--format", "excellon",
            "--drill-origin", "absolute", "--excellon-separate-th",
            "--excellon-zeros-format", "decimal",
            "--excellon-oval-format", "route", "-o", route_dir + "/", PCB)
        # Renamed so it can never be mistaken for the file already reviewed.
        shutil.copy2(os.path.join(route_dir, "sd-net-PTH.drl"),
                     os.path.join(alt_dir, "sd-net-PTH-M15M16.drl"))

        # Drill plotted as Gerber, so the slots are visible in any viewer.
        gbr_dir = os.path.join(tmp, "gbr")
        os.makedirs(gbr_dir)
        run("pcb", "export", "drill", "--format", "gerber",
            "--drill-origin", "absolute", "-o", gbr_dir + "/", PCB)
        for name in ("sd-net-PTH-drl.gbr", "sd-net-NPTH-drl.gbr"):
            src = os.path.join(gbr_dir, name)
            if os.path.exists(src):
                _strip_x2(src, os.path.join(alt_dir, name))

        alt_zip = os.path.join(PCBWAY_OUT, "sd-net-2.0-drill-alternates.zip")
        with zipfile.ZipFile(alt_zip, "w", zipfile.ZIP_DEFLATED) as z:
            for f in sorted(os.listdir(alt_dir)):
                z.write(os.path.join(alt_dir, f), f)

        n_main = len(zipfile.ZipFile(main_zip).namelist())
        n_alt = len(zipfile.ZipFile(alt_zip).namelist())

    open(os.path.join(PCBWAY_OUT, "README.md"), "w").write(PCBWAY_README)

    print(f"rs274x       : {n_main} files -> "
          f"{os.path.relpath(main_zip, HERE)}")
    print(f"alternates   : {n_alt} files -> "
          f"{os.path.relpath(alt_zip, HERE)}")


def copy_to(dest):
    os.makedirs(dest, exist_ok=True)
    for name in sorted(os.listdir(OUT)):
        src = os.path.join(OUT, name)
        dst = os.path.join(dest, name)
        if os.path.isdir(src):
            shutil.rmtree(dst, ignore_errors=True)
            shutil.copytree(src, dst)
        else:
            shutil.copy2(src, dst)
    print(f"copied package -> {dest}")


def listing(path):
    print(f"\npackage: {os.path.relpath(path, HERE)}/")
    for f in sorted(os.listdir(path)):
        p = os.path.join(path, f)
        if os.path.isfile(p):
            print(f"   {f:34s} {os.path.getsize(p)/1024:7.1f} KB")


def main():
    args = sys.argv[1:]

    # --pcbway builds the vendor variant alone, leaving fab/v2.0-kicad/ as it
    # is. That matters while an order is in audit: regenerating the canonical
    # package would restamp every timestamp for no change in the data.
    if "--pcbway" in args:
        build_pcbway()
        listing(PCBWAY_OUT)
        return

    os.makedirs(OUT, exist_ok=True)
    build()
    for extra in args:
        copy_to(extra)
    listing(OUT)


if __name__ == "__main__":
    main()

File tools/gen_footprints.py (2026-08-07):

#!/usr/bin/env python3
"""Generate the three KiCad footprints this project needs and KiCad does not ship.

KiCad ships no footprint matching any of the three parts on this board. It does
carry six full-size SD sockets, but none match the SD-006M's contact count or
mounting; it has USB-A receptacles rather than a board-mounted male plug; and an
0804 LED is outside the metric chip series. All three are defined here.

Every dimension below is taken from the manufacturer's recommended land pattern:

  SD-006M         SOFNG, LCSC C125615, datasheet page 2 "CIRCUIT BOARD SIZE"
  USB-AM90        Shou Han, LCSC C404965, drawing A/0 dated 2018.07.10
  LED-12-215SYGC  Everlight 12-215SYGC/S530-E2/TR8, LCSC C131283, 0804 body

Conventions:

  Coordinates are millimetres in the footprint's own frame, Y positive downward.
  Pad 1 of the LED is the cathode, matching KiCad's Device:LED symbol.
  Slots are plated oval openings given as (width, height).

    ./tools/gen_footprints.py        # writes hardware/sd-net.pretty/

Verified geometry and the reasoning behind each correction: docs/LAND-PATTERNS.md
"""

import math
import os

HERE = os.path.dirname(os.path.dirname(os.path.abspath(__file__)))
PRETTY = os.path.join(HERE, "hardware", "sd-net.pretty")
FP_VERSION = 20260206


def pad(name, x, y, w, h, shape="rect", drill=0.0, slot=None):
    return {"name": name, "x": x, "y": y, "w": w, "h": h,
            "shape": shape, "drill": drill, "slot": slot}


# --- SD-006M ----------------------------------------------------------------
# Eleven contacts in one row, two shell tabs, two non-plated locating pegs.
#
# The contact row sits 24.60 mm from the peg holes, which are 24.20 mm apart and
# define where the socket actually lands. Contact X positions are referenced to
# pad 9: #1 at 2.50, #2 at 5.00, CD at 6.43, #3 at 8.30, #4 at 10.00, then 2.50
# to #5 and to #6, 2.43 to #7, 1.70 to #8, and 3.25 to WP.
#
# Contact pads are drawn 2.1996 mm tall against a specified 2.00, and the shell
# tabs 1.999 x 2.3012 against 1.70 x 2.00. The extra length is solder fillet and
# is deliberate; DRC clearance is unaffected.
_SD_PEG_Y = 13.076
_SD_ROW_Y = round(_SD_PEG_Y - 24.60, 4)
_SD_W, _SD_H = 1.1989, 2.1996
# Listed in pad-number order; physical order along the row is
# WP, 8, 7, 6, 5, 4, 3, CD, 2, 1, 9.
_SD_X = {"1": 6.7793, "2": 4.2799, "3": 0.9804, "4": -0.7214, "5": -3.2207,
         "6": -5.7201, "7": -8.1509, "8": -9.8501, "9": 9.2786,
         "CD": 2.8486, "WP": -13.1014}

SD_006M = [pad(n, x, _SD_ROW_Y, _SD_W, _SD_H) for n, x in _SD_X.items()]
SD_006M += [
    # Shell tabs. Not mirror images of each other: the right tab sits further
    # out and 1.20 mm nearer the contact row than the left.
    pad("12", 14.582, 9.7739, 1.999, 2.3012),
    pad("13", -14.0005, 10.9753, 1.999, 2.3012),
]
SD_006M_NPTH = [(12.100, _SD_PEG_Y, 1.6), (-12.100, _SD_PEG_Y, 1.6)]

# --- USB-AM90 ---------------------------------------------------------------
# Four signal pins at 2.50 / 2.00 / 2.50, spanning 7.00 overall, in 1.00 mm
# holes. The locating pegs and the shell tabs share one line 2.00 mm from the
# pin row.
#
# The shell ends in two flat 0.86 mm tabs, not mounting posts. They belong in
# slots at +/-5.855, cut here 0.04 mm over the specified 0.86 x 2.20 to leave
# room for hole plating. These tabs are the board's only mechanical anchorage.
#
# Peg clearance is tight: a 0.85 mm peg in a 1.00 mm hole leaves 0.05-0.075 mm
# radially, so the 2.00 mm offset has to be exact or the plug will not seat.
_USB_ROW_Y = -1.0008
_USB_TAB_Y = 1.0008

USB_AM90 = [
    pad("1", 3.5001, _USB_ROW_Y, 1.6002, 1.6002, "circle", drill=1.0008),
    pad("2", 1.0008, _USB_ROW_Y, 1.6002, 1.6002, "circle", drill=1.0008),
    pad("3", -0.9982, _USB_ROW_Y, 1.6002, 1.6002, "circle", drill=1.0008),
    pad("4", -3.5001, _USB_ROW_Y, 1.6002, 1.6002, "circle", drill=1.0008),
    pad("MH1", 5.855, _USB_TAB_Y, 1.70, 3.05, drill=2.601, slot=(0.90, 2.25)),
    pad("MH2", -5.855, _USB_TAB_Y, 1.70, 3.05, drill=2.601, slot=(0.90, 2.25)),
]
USB_AM90_NPTH = [(2.250, _USB_TAB_Y, 1.0), (-2.250, _USB_TAB_Y, 1.0)]

# --- LED-12-215SYGC ---------------------------------------------------------
# An 0804 body, 2.0 x 1.0 mm, a size outside the metric chip series. The
# terminals sit 0.60-1.00 mm out from the centre, which a stock 0603 land does
# not reach. Pad 1 is the cathode and is placed on -x.
LED_12_215SYGC = [
    pad("2", 1.0503, 0.0, 0.8992, 0.8001),
    pad("1", -1.0503, 0.0, 0.8992, 0.8001),
]


def npth_sexp(x, y, d):
    return (f'\t(pad "" np_thru_hole circle\n'
            f'\t\t(at {x} {y})\n'
            f'\t\t(size {d} {d})\n'
            f'\t\t(drill {d})\n'
            f'\t\t(layers "F&B.Cu" "*.Mask")\n'
            f'\t)\n')


def pad_sexp(p):
    if p.get("slot"):
        sw, sh = p["slot"]
        return (f'\t(pad "{p["name"]}" thru_hole oval\n'
                f'\t\t(at {p["x"]} {p["y"]})\n'
                f'\t\t(size {p["w"]} {p["h"]})\n'
                f'\t\t(drill oval {sw} {sh})\n'
                f'\t\t(layers "*.Cu" "*.Mask")\n'
                f'\t)\n')
    if p["drill"] > 0:
        return (f'\t(pad "{p["name"]}" thru_hole {p["shape"]}\n'
                f'\t\t(at {p["x"]} {p["y"]})\n'
                f'\t\t(size {p["w"]} {p["h"]})\n'
                f'\t\t(drill {p["drill"]})\n'
                f'\t\t(layers "*.Cu" "*.Mask")\n'
                f'\t)\n')
    return (f'\t(pad "{p["name"]}" smd {p["shape"]}\n'
            f'\t\t(at {p["x"]} {p["y"]})\n'
            f'\t\t(size {p["w"]} {p["h"]})\n'
            f'\t\t(layers "F.Cu" "F.Mask" "F.Paste")\n'
            f'\t)\n')


def courtyard(pads, margin=0.5):
    xs = [p["x"] - p["w"] / 2 for p in pads] + [p["x"] + p["w"] / 2 for p in pads]
    ys = [p["y"] - p["h"] / 2 for p in pads] + [p["y"] + p["h"] / 2 for p in pads]
    x0, x1 = min(xs) - margin, max(xs) + margin
    y0, y1 = min(ys) - margin, max(ys) + margin
    out = ""
    for layer, width in (("F.CrtYd", 0.05), ("F.Fab", 0.1)):
        out += (f'\t(fp_rect\n\t\t(start {x0:.3f} {y0:.3f})\n'
                f'\t\t(end {x1:.3f} {y1:.3f})\n'
                f'\t\t(stroke (width {width}) (type default))\n'
                f'\t\t(fill no)\n\t\t(layer "{layer}")\n\t)\n')
    return out, (x0, y0, x1, y1)


def cathode_silk(pads, margin=0.35, half=0.65, width=0.12):
    """Silkscreen bar outside pad 1, marking the cathode.

    Chip LEDs carry no legible marking once placed, so the board has to state
    polarity or assembly is guessing.
    """
    k = next(p for p in pads if p["name"] == "1")
    x = k["x"] + math.copysign(k["w"] / 2 + margin, k["x"])
    return (f'\t(fp_line\n\t\t(start {x:.4f} {-half})\n\t\t(end {x:.4f} {half})\n'
            f'\t\t(stroke (width {width}) (type solid))\n'
            f'\t\t(layer "F.SilkS")\n\t)\n')
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

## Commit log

2026-07-31 set up sd-net repo: freeze rev 1.5 artifacts, document defect and migration plan
    Imports the EasyEDA Pro rev 1.5 outputs (Gerbers, BOM, pick-and-place,
    flying-probe, schematic PDF) as a frozen reference, plus the OSHW branding
    assets. Adds notes on the GL823K power-rail defect, docs/MIGRATION.md
    for the Pro -> Altium -> KiCad route, and docs/MANUFACTURING.md.
    [BOM_sd - net 1.5_sd - net 1.5_2026-06-19.xlsx, PickAndPlace_sd _ net 1_5_2026_06_19.xlsx]
2026-07-31 extract rev 1.5 measured baseline from fabricated Gerbers and BOM
    Adds tools/xlsx2csv.py and tools/gerber_bbox.py (stdlib only) to pull the
    EasyEDA exports into diffable form, plus docs/REV1.5-BASELINE.md recording
    the 11-placement BOM, component coordinates and mechanical envelope that
    rev 2.0 must be checked against.
    Two findings that affect the assembly quote: USB1 is a through-hole AM90
    connector, and the board is a shaped 113.85 x 74.56 mm outline rather than
    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
    [BOM_v1.5.csv, PickAndPlace_v1.5.csv]
2026-07-31 establish GL823K power topology from the datasheet
    The Rev 1.05 datasheet has no Typical Application Circuit, so the verification
    gate named in RESUME_NOTES.md cannot be satisfied as written. It does settle
    the topology on its own: section 5.2/5.3 list 5V as the sole supply, and
    section 4.6 describes an on-chip 5V-to-3.3V band-gap regulator feeding the USB
    PHY and PMOS.
    VDD (pin 9) and VDDA (pin 13) are therefore regulator outputs, not supply
    inputs, and PMOS (pin 8) is a switched output. Rev 1.5 shorted all three
    together. This supersedes the three-equivalent-rails prescription in
    RESUME_NOTES.md.
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2026-07-31 resolve the VDD/VDDA question: decouple separately, never link
    No verified second-source schematic could be obtained -- OSHWLab renders only
    in the EasyEDA editor, the EasyEDA API returns 403, and the EEWorld, Scribd
    and PCBWay pages yield no content to a fetcher. Records what was checked so
    the search is not repeated.
    The question turns out not to need answering. Separate decoupling with no
    external link between pin 9 and pin 13 is correct whether or not they share an
    internal node, whereas linking them is only safe if they do. Also flags an
    unverified search-engine claim about an AP2112 3.3V LDO, which appears to
    belong to a different (SD-WiFi) board and would fight the on-chip regulator.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
2026-07-31 recover the full rev 1.5 netlist from the Altium ASCII export
    KiCad's Altium importer rejects the EasyEDA Pro export: it wants the binary
    OLE .PcbDoc, and EasyEDA Pro emits Altium ASCII 5.0. Documented in MIGRATION.md
    with the exact error.
    The ASCII is pipe-delimited text, so tools/altium_netlist.py reads the
    connectivity directly instead. All 11 components and 13 nets recovered. The
    audit shows every SD contact, both USB data lines, the grounds and the LED
    topology are correct -- the entire rev 1.5 failure is net $1N2351, which is a
    third independent confirmation after the .tel netlist and flying-probe data.
    [Schematic1P1.schdoc, sd - net 1.5.pcbdoc]
2026-07-31 add the rev 2.0 KiCad schematic with the power-rail fix
    Builds hardware/sd-net.kicad_sch from the recovered rev 1.5 netlist rather than
    importing it, so the four power nodes are separate because they are declared
    separate. Pin types carry the datasheet finding: VDD, VDDA and PMOS are
    power_out, 5V is the only power_in.
    Project-local symbols for GL823K, SD-006M and USB-AM90; U1 lands on KiCad's
    stock SSOP-16_3.9x4.9mm_P0.635mm, an exact match for the datasheet package.
    Deliberately floating pins carry no-connect markers so a future reader can tell
    them from oversights.
    ERC is clean apart from two warnings for the not-yet-created footprint library.
    tools/verify_netlist.py confirms all 15 net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
    [sd-net.kicad_sch]
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2026-07-31 emit KiCad 10 schematic format and stop designator text colliding
    Two fixes from opening the schematic in the GUI for the first time.
    KiCad 10 writes .kicad_sch version 20260306; the generator was emitting the 9.0
    format 20250114, which loaded but triggered an "older version of KiCad"
    conversion banner. Discovered the number by running kicad-cli sch upgrade, and
    the generator now emits it directly -- ERC and the netlist check still pass.
    Reference and value text was placed at a fixed offset tuned for the tall custom
    symbols, which threw R1's and LED1's designators 22.86 mm up into the capacitor
    row. Text placement is now per-symbol: above the big parts, to the right for the
    two-pin Device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
    [sd-net.kicad_sch]
2026-07-31 fix pin-side mapping for horizontal symbols
    A pin's angle gives the direction from its connection point toward the symbol
    body, so the connection sits on the opposite side. The stock-symbol path only
    distinguished 270 from everything else, which is right for the vertical
    Device:C and Device:R but wrong for Device:LED, whose pins are horizontal
    (0/180). LED1 ended up with both net labels rotated vertically and its
    designator text overlapping LED_A.
    Now maps all four angles, and LED1's text sits above the part rather than to
    the right where its own pin label lives. ERC and the netlist check still pass.
    [sd-net.kicad_sch]
2026-07-31 add C7 and C8 so all four power rails get proper decoupling
    Rev 1.5's six capacitors stretch to three rails, not the four the fixed
    topology needs: VCARD had bulk but no high-frequency cap, and VDDA had a single
    100 nF and no bulk. C7 (VCARD) and C8 (VDDA) are the same 100 nF 0603 as
    C4/C5/C6, LCSC C14663, so no new line item -- 11 placements becomes 13.
    The capacitor row in the schematic is regrouped by rail. tools/verify_netlist.py
    now separates pads that were floating in rev 1.5 from parts that did not exist
    in it, so the two show up honestly in the diff rather than both reading as
    'newly connected'. ERC clean, netlist verified.
    [sd-net.kicad_sch]
2026-07-31 stop downward net labels colliding with their own symbols
    Global labels below a pin were justified so they rendered back up over the part
    they belong to: R1's LED_A sat on the resistor body and PWR_FLAG's GND was
    inside the flag graphic. Flipped the justification on downward labels, then
    moved R1, LED1 and the flag into their own row -- R1 had been directly below
    C1, so once the labels pointed the right way C1's GND ran into R1's VDD.
    Verified by rendering the PDF and inspecting it rather than by eye. ERC clean,
    netlist unchanged and still passing.
    [sd-net.kicad_sch]
2026-07-31 record why the design has no card detect
    The GL823K datasheet feature list advertises 'Support non-SD Card Detect pin,
    non-MS Insertion/Removal pin design to save BOM cost' and the same for write
    protection. The chip polls the SD bus instead, so the socket's mechanical CD
    and WP contacts are correctly left unconnected -- a designed-in choice rather
    than an oversight in rev 1.5.
    Also notes that pin 11 is a plain GPIO with no documented card-presence
    function, so wiring CD to it would be decoration, and that CARD1.1 is rightly
    used as DAT3 since its card-detect role only applies in SPI mode.
2026-07-31 derive SD-006M and USB-AM90 footprints from the fabricated board
    KiCad has no stock footprint for either part. Rather than draw them against a
    datasheet, tools/gen_footprints.py lifts the pad geometry out of the Altium
    ASCII export of rev 1.5 -- pads known to match the physical parts, since boards
    were built with them.
    Three coordinate conventions collide: Altium is absolute mils with Y up, a
    footprint is defined in the component's own frame so the placement rotation has
    to be undone, and KiCad footprints are mm with Y down. The generator inverts
    its own transform and compares against the original absolute pad positions;
    worst-case round-trip error is 0.057 um, which is the 4-decimal roundi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
    [gen_footprints.py]
2026-07-31 add the missing NPTH mounting holes to both connector footprints
    Neither connector would have seated. EasyEDA exported the mechanical holes as
    board-level NPTH drills rather than component pads, so they never appeared in
    the Pad records that gen_footprints.py reads, and the first cut of both
    footprints silently omitted them.
    Recovered from Drill_NPTH_Through.DRL: two 1.0 mm locating pegs for the AM90
    plug, 4.5 mm apart and centred on USB1's x; two 1.6 mm mounting pegs for the SD
    socket, 24.2 mm apart and centred on CARD1's x. Positions round-trip back to
    the drill file within 0.3 um.
    [gen_footprints.py]
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2026-07-31 add the rev 2.0 board: triangle outline, 4-layer stackup, placement and nets
    tools/gen_pcb.py produces an unrouted hardware/sd-net.kicad_pcb with all 13
    footprints placed and every pad bound to its net.
    Edge.Cuts reproduces rev 1.5's triangle from the fabricated Gerber -- flat base,
    two 4.846 mm corner fillets, two diagonals, and a 13.544 mm-radius apex arc. It
    excludes the 12.40 x 15.40 mm rectangle that also sits on that Gerber layer:
    that rectangle is centred on USB1, overlaps the board edge by about a
    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
    [sd-net.kicad_pcb]
2026-07-31 put component values on the board instead of footprint names
    A .kicad_mod's Value property holds the footprint name, and gen_pcb.py embedded
    it unchanged -- so every part on the board read C_0805_2012Metric or
    SSOP-16_3.9x4.9mm_P0.635mm rather than 10uF or GL823K-HCY04. The value was
    already being passed into place(); it just was not used. Beyond cluttering the
    canvas this would have produced a meaningless fab BOM.
    [sd-net.kicad_pcb, sd-net.kicad_sch]
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2026-07-31 rotate the HF decoupling caps so their live pad faces the chip
    C4, C5 and C6 sat with pad 1 -- the rail pad -- pointing away from U1, so the
    ground pad was the one nearest the pin. Rotating them 180 degrees shortens the
    live path by the pad pitch without moving anything: +5V 5.96 -> 4.46 mm, VDD
    6.53 -> 5.20, VDDA 6.22 -> 5.24. Pad 2 is GND and vias straight into the plane,
    so it does not care about sitting further out.
    C3 also pulled in to 8.58 mm. Both VCARD caps now sit on the chip side, 5.95
    and 8.58 mm from U1 pin 8 rather than at the socket -- fine for a switched
    200 mA rail over this trace length.
    Placement complete. DRC is 2 cosmetic warnings plus the 37 unrouted nets.
    [sd-net.kicad_pcb]
2026-07-31 pour ground planes and route the USB differential pair
    tools/route.py adds copper additively -- it strips only what it previously
    generated (tagged by uuid prefix) and re-adds, so hand placement and any hand
    routing survive. It never touches footprints.
    GND is poured on all four layers. The F.Cu pour connects every surface-mount
    ground pad directly, so none of them need their own via; In1/In2 give the USB
    pair an unbroken reference plane; ten stitching vias tie the layers together.
    That alone takes unconnected items from 37 to 22.
    The USB pair stays on F.Cu end to end -- no vias, no layer change, no plane
    split under it. It has to invert on the way: at U1 the pins are stacked 0.635 mm
    apar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
    [sd-net.kicad_pcb]
2026-07-31 target PCBWay: record their stackup and fix the pair to 90 ohm
    PCBWay standard 4-layer 1.6 mm is 7628 prepreg at 0.1855 mm after lamination,
    Dk 4.74, over a 1.03 mm core, 1 oz copper, ENIG. That stackup is now recorded
    on the board rather than left to KiCad's generic defaults.
    Against those real numbers the differential pair was wrong. At 0.20 mm width
    and 0.25 mm spacing, IPC-2141 microstrip gives Z0 61.0 ohm and Zdiff 105.9 ohm
    -- nowhere near the 90 ohm USB 2.0 wants, and the kind of error that surfaces
    as marginal or intermittent enumeration rather than an obvious failure.
    Solved for the real stackup: 0.30 mm traces at 0.346 mm spacing give Zdiff
    90.0 ohm. The pair threads the 1.475 mm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
    [sd-net.kicad_pcb]
2026-07-31 rotate U1 to 270 so the pin rows face the parts they serve
    At 180 degrees U1's pin rows were vertical columns -- power left, SD right --
    so the SD bus had to come down from the socket and wrap around the chip. At 270
    the rows run horizontally: pins 1-8 (almost all SD) face CARD1 above, pins 9-16
    (USB and power) face USB1 below.
    The ordering then falls out almost free. Six of the seven signals leave the
    socket in the same left-to-right order they arrive at U1, so straight diagonals
    between them provably cannot cross. Only VCARD is out of order and needs a
    layer change.
    Two bugs found on the way, both mine:
    The rotation matrix. KiCad applies [[cos,sin],[-sin,cos]] -- opposite handedness
    to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
    [sd-net.kicad_pcb]
2026-07-31 rebuild the board clean: no copper, corrections folded into the generator
    Full reset of hardware/sd-net.kicad_pcb -- no tracks, no vias, no zones. Just
    outline, stackup, placement and nets, ready to route from scratch.
    Three things carried forward, because they are corrections rather than choices:
    Pad angles. gen_pcb.py now stamps the footprint's rotation onto every pad.
    KiCad stores pad angles absolutely, so rotating a footprint without this moves
    pad positions but leaves pad shapes unrotated -- which at 270 degrees laid U1's
    1.65 mm pads across a 0.635 mm pitch and shorted the part to itself.
    U1 at 270 degrees. Its pin rows now run horizontally: pins 1-8 face CARD1
    above, pins 9-16 face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
    [sd-net.kicad_pcb]
2026-07-31 tidy the layout: centreline stack, even cap rows, quieter silkscreen
    Reworked placement for appearance as much as electrics. CARD1, U1 and USB1 sit
    on the board's axis of symmetry at x=88.3 rather than scattered within a
    millimetre of it. The eight capacitors form two even rows below U1 -- 0603 high
    frequency on 2.0 mm pitch, 0805 bulk on 2.4 mm -- all one orientation, instead
    of an ad-hoc cluster.
    Getting them tidy also got them close: the caps that matter are now 1.60-2.25 mm
    from the pins they decouple, against 5-7 mm before, and C7 sits 3.16 mm under
    the card's power contact.
    Silkscreen carries designators for U1, CARD1 and USB1 only. The ten passives
    keep theirs on F.Fab, which is doc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
    [sd-net.kicad_pcb]
2026-07-31 wrap the decoupling around U1 instead of stacking it in rows
    The high-frequency caps stay tight along U1's bottom edge, where its power pins
    are. The three bulk caps climb the chip's left flank, which is free of pads at
    270 degrees -- pads exist only on the top and bottom rows -- and sits clear of
    the SD fan, which stays above y 79.4. Rot 180 turns their pad 1 inward.
    A true ring around the package is not possible and would not be worth it: the
    GL823K's supply pins are bunched within 2.54 mm of each other on one edge, so
    spreading caps evenly around it moves them away from what they decouple. A
    radial arrangement would put C5 and C4 nearly on top of each other. Wrapping one
    extra flank spen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
    [sd-net.kicad_pcb]
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2026-08-07 warn against Update Footprints from Library; it would short the board
    The two 'does not match copy in library' warnings are harmless in themselves.
    USB1's pads are identical to the library copy as a set and merely reordered;
    CARD1's differ only by an angle of 180 on shapes symmetric under it.
    But they are the visible symptom of something that is not harmless. KiCad stores
    pad angles absolutely, so U1 at 270 and CARD1 at 180 carry angles their library
    copies lack. Running the library update would replace the instances with the
    library versions, leaving pad positions rotated and pad shapes not -- which puts
    U1's 1.65 mm pads across a 0.635 mm pitch. Tested by stripping the angles: 102
    violati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
    [sd-net.kicad_pcb]
2026-08-07 clear CARD1's library mismatch; USB1's is cosmetic
    CARD1's pads carried a stamped 180 degree angle its library copy lacked. Its
    pads are rectangles and circles, all symmetric under 180, so the angle was a
    no-op there -- unlike U1 at 270, where it is load-bearing. Removing it makes the
    instance match, and DRC confirms no shorts appeared.
    USB1's warning survives. Its pad geometry is byte-identical to the library as a
    set, verified pad by pad; what differs is element ordering and whitespace, which
    KiCad's comparator is sensitive to. Also reordered the library's NPTH pads to
    match the order KiCad writes, which did not settle it.
    Not chasing it further: the geometry is verified equal, so the wa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
    [sd-net.kicad_pcb]
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2026-08-07 correct four footprints against the manufacturers' land patterns
    gen_footprints.py built SD-006M, USB-AM90 and the LED land from rev 1.5's
    fabricated pads, on the reasoning that pads boards were built with must match
    the physical parts. Rev 1.5 never enumerated, so that reasoning was never
    actually tested. Measured against the manufacturers' own recommended layouts,
    four things were wrong.
    SD-006M: the contact row sat 24.05 mm from the mounting pegs; the datasheet
    says 24.60. The pegs locate the socket, so the tails were landing ~0.55 mm off
    the pads -- about 78% overlap on a 2.0 mm tail. Marginal rather than fatal,
    which is exactly why nothing caught it. Confirmed three ways: the printed 2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
    [sd-net.kicad_pcb, sd-net.kicad_sch]
2026-08-07 measure VDD/VDDA on hardware: 3.38 V, the regulator is real
    The reading behind rev 2.0's entire power topology was reasoned from the
    datasheet and never confirmed. It is confirmed now.
    A rev 1.5 board on a 5 V phone charger, VBUS at 5.17 V and inside Table 5.2's
    4.75-5.25 V, puts the shorted pin-8/9/13 node at 3.38 V against ground. Nothing
    external feeds that node -- VBUS is the board's only supply and it lands on pin
    10 alone -- so 3.38 V can only be produced inside the chip. The on-chip 5V to
    3.3V band-gap regulator of section 4.6 is real, it runs, and it drives those
    pins. 3.38 V is within the +/-3% expected of a band-gap part, so it is
    regulating rather than leaking.
    VDD and VDDA are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
2026-08-07 widen the GND zone to the new outline; reposition the USB1 label
    Hand edits in the PCB editor. The zone one is a real fix: making the outline
    symmetric moved the board's right edge out to 146.36, but the GND zone still
    stopped at 146, leaving a 0.36 mm strip of board with no pour on it. Not a DRC
    error, since zones are not required to reach the edge, but a gap that should
    not have survived the outline change. The zone now spans 29 to 147.5 against a
    board of 30.24 to 146.36, covered with margin on both sides.
    USB1's reference designator moves off the connector body and goes bold.
    [sd-net.kicad_pcb]
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2026-08-07 untrack notes that duplicate docs/
    Everything in them that matters to a reader is already in docs/ -- the power
    topology in
    POWER-DESIGN, the rev 1.5 failure in the same file, the footprint corrections
    in FOOTPRINT-AUDIT, and the ordering caveats in BEFORE-ORDERING.
    Untracked rather than deleted: the files stay on disk and keep working, they
    just stop travelling with the repo.
2026-08-07 add a front page for the repository
    The repo had no README at all, so its GitHub page was a bare file list. For a
    project meant to be replicated by other people, that is the wrong first
    impression.
    Covers what the board is, the fact that rev 2.0 has never been fabricated,
    what rev 1.5 did wrong and how that was measured rather than guessed, the
    directory layout, how to regenerate the fab package, and a pointer to
    BEFORE-ORDERING for anyone about to spend money.
    The licence badge points at cern-ohl.web.cern.ch rather than a local file,
    because there is no LICENSE file in the repo yet. An OSHWA-certified project
    under CERN-OHL-S-2.0 should carry the licence text, so that is still worth
    addin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
2026-08-07 add the CERN-OHL-S-2.0 text, and drop em dashes throughout
    Two things, both housekeeping.
    The repo claimed CERN-OHL-S-2.0 and carried an OSHWA UID without ever including
    the licence. LICENSE is the official text fetched from the CERN OHL project, not
    retyped, since that is not text to paraphrase.
    Em and en dashes are gone from every markdown file and every generator, 196 of
    them. Replacements were chosen by context rather than swapped blind: a colon
    where the clause after the dash explains the one before it, a comma otherwise,
    and a plain hyphen inside numeric ranges. A second pass promoted 11 of the
    resulting comma splices to semicolons where the second half had its own subject
    and verb.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
    [gen_fab.py, gen_footprints.py, gen_pcb.py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]
2026-08-07 trim the repository to what reproducing the board requires
    The repository now presents the finished design rather than the process that
    produced it. Working notes, vendor strategy and the migration log are gone;
    everything required to rebuild the board remains.
    Documents are specification, not narrative. POWER-DESIGN states the supply
    topology and why VDD and VDDA are outputs. LAND-PATTERNS replaces the footprint
    audit with a dimension table for all three generated footprints, each value
    attributed to its manufacturer drawing. STATUS replaces the ordering notes with
    what is verified, what is not, and the first-article checks.
    gen_footprints.py no longer parses the rev 1.5 Altium export. Pa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
    [BOM_sd - net 1.5_sd - net 1.5_2026-06-19.xlsx, BOM_v1.5.csv, PickAndPlace_sd _ net 1_5_2026_06_19.xlsx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]
2026-08-07 correct the claim about KiCad's stock SD footprints
    KiCad ships six full-size SD socket footprints in Connector_Card, from TE,
    Hirose and Kyocera. Three files stated it ships none. The error came from
    checking the 3D model directory, which does hold microSD and nanoSIM only, and
    generalising that to footprints.
    The conclusion is unaffected: none of the six share the SD-006M's contact count,
    shell tabs or peg positions, and full-size SD sockets are not interchangeable
    between manufacturers, so a part-specific footprint was still required. Only the
    stated reason was wrong.
    Corrected in LAND-PATTERNS.md and both generator docstrings.
    [gen_footprints.py]
2026-08-07 ask the fab to populate USB1, and point at the renamed repo
    The through-hole note read as "quote the hand-soldering so we can decide",
    which left room to ship the plug loose. State plainly that every board
    should arrive with USB1 fitted.
    Repository URL follows the rename to sd-net-2.0. Both changes are made in
    gen_fab.py as well, so regenerating the package keeps them.
    [gen_fab.py]
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2026-08-07 point the silkscreen at phonetucked.dev instead of a superseded UID
    US002797 certifies rev 1.5, not rev 2.0, and its listing wrongly claims LED
    card detection. Rev 2.0 was submitted for its own certification on 2026-08-02
    and no UID has been issued, so the board carries a project URL rather than
    waiting on a manual review queue or stamping a dead one.
    : front silkscreen now reads phonetucked.dev/sd-net-2-0
    : UID dropped from the fab package README, via tools/gen_fab.py
    : OSHWA badge dropped from the front page, CERN-OHL-S-2.0 badge kept
    The gear mark needs no number, so the certification stays on OSHWA's listing.
    DRC 0 violations, 0 unconnected. verify_netlist.py PASS.
    [sd-net.kicad_pcb]
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
